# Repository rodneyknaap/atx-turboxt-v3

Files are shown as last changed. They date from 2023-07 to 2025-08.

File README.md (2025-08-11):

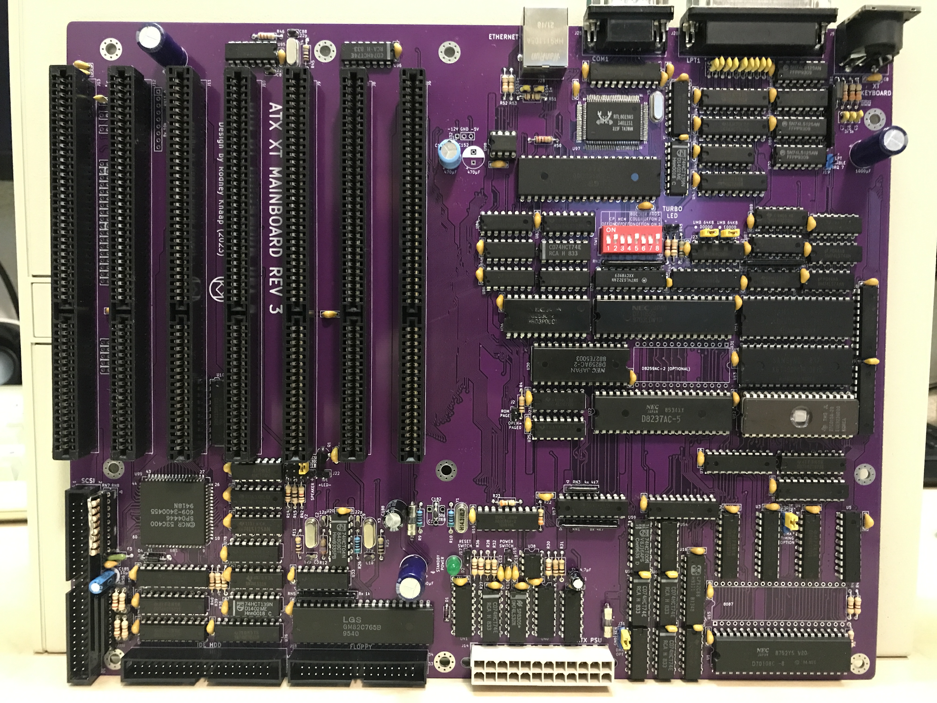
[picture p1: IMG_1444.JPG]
Photo of the assembled ATX Turbo XT mainboard V3 PCB


# ATX Turbo-XT Mainboard V3

I hereby publish the third revision of my ATX Turbo-XT mainboard design.
I had my doubts whether it would be wise to share my project, however the fact that keeping technology to myself prevents others to benefit from it made me decide for a release.
Open source is in my opinion the most important concept for all technology of mankind to move into the future in a way which has the potential to benefit all of us.

## Purpose and permitted use, cautions for a potential builder of this design

This project was created for historical purposes out of love for historical computing designs and for the purpose of enabling computing enthousiasts with a sufficient level of building and troubleshooting expertise to be able to experience the technology by building and troubleshooting the hardware described in this project.

## Besides the GPL3 license there are a few warnings and usage restrictions applicable:

No guarantees of function or fitness for any particular or useful purpose is given, building and using this design is at the sole responsibility of the builder.

Do not attempt this project unless you have the necessary electronics assembly expertise and experience, and know how to observe all electronics safety guidelines which are applicable.

It is not permitted to use the computer built from this design without the assumption of the possibility of loss of data or malfunction of the connected device. To be used strictly for personal hobby and experimental purposes only. No applications are permitted where failure of the device could result in damage or injury of any kind.

If you plan to use this design or any part of it in new designs, the acknowledgement of the designer and the design sources and inspirations, historical and modern, of all subparts contained within this design should be included and respected in your publication, to accredit the hard work, time and effort dedicated by the people before you who contributed to make your project possible.

No guarantee for any proper operation or suitability for any possible use or purpose is given, using the resulting hardware from this design is purely educational and experimental and not intended for serious applications. Loss of data is likely and to be expected when connecting any storage device or storage media to the resulting system from this design, or when configuring or operating any storage device or media with the system of this design.

When connecting this system to a computer network which contains stored information on it, it is at the sole responsibility and risk of the person making the connection, no guarantee is given against data loss or data corruption, malfunctions or failure of the whole computer network and/or any information contained inside it on other devices and media which are connected to the same network.

When building this project, the builder assumes personal responsibility for troubleshooting it and using the necessary care and expertise to make it function properly as defined by the design. 
You can email me with questions, but I will reply only if I have time and if I find the question to be valid. Which will probably also lead to an update here.
I want to primarily dedicate my time to new project development, I am not able to do any user support, so that's why I provide the elaborate info here which will be expanded if needed.

# Factors for proper operation and stability

Timing issues are likely to occur which require certain components to be of a suitable sufficient type to be able to meet the timing requirements for proper function. The prototype of the developer is proof of concept, please refer to the detailed partslist provided which includes type and manufacturer for all ICs where necessary, however each new build may pose it's own challenges to bring it to success. This design is by nature not a turnkey solution and will only function when using all the components of similar timing and behaviour as was used in the prototype. Determining the right components may likely be experimental in nature and require expertise, experience, effort and persistance.

Specifically the databus control transceivers and DMA handshaking circuits are most sensitive to exact types of at least equivalent timing as the types specified in the IC list, so refer to that list. The choice of DMA controller is a matter of trial and error, not all DMA controller chips are of sufficient timing to control a floppy disk using this design, specifically a floppy disk format poses the most exact testing situation to ensure proper DMA operation. Manufacturing date variations also may result in timing variations of the DMA controller. If the DMA handshake logic ICs are of faster types, this may also allow a more broad range of DMA controller ICs to work properly. Though I have not verified this with tests. Theoretically, using lower voltage logic or programmable logic may provide faster timing, though I have not chosen these methods in my design because I already achieved proper timing with the components I had available.

The 24Mhz oscillator load capacitors should be used as specified in the design, the oscillator should be checked to operate properly. If the total load (PCB capacitance + load capacitors) is too high, the oscillator will not run reliably and this will cause crashes, devide by zero errors, freezing, resets etc. Therefore ensure to observe the load capacitance suitable and proper stable operation of the oscillator. The ground shielding of the PCB traces of the clock signals comprise an addition to the load capacitance so the load capacitors themselves can be lower. For a turbo XT, it is not required to use two 8284 chips, one is sufficient. The DMA controller can properly operate on a fixed 50% duty cycle clock within the speed range of the chip so that is what I have provided. I derived the XT system clocks (keyboard, timer chip) from the DMA clock signal, which are also all fixed clock signals and do not vary when switching the CPU speed. CPU speed can be switched with the keyboard CTRL-ALT-num+ and CTRL-ALT-num- as controlled by the Super PC/Turbo XT BIOS (perfected by Jon Petrosky and Ya'akov Miles) at any moment without crashing the CPU. At least, I was not able to get the PC to crash by switching the speed at various moments.

# Important notice about capacitors at edge of mainboard
There have been many capacitor footprints added to the edge of the ISA bus, on the left of the mainboard. These do not all need to be populated, but are instead intended for termination of signal reflections, in case there are some issues occuring. Specifically, active high signals may be sensitive to noise generated from reflections. The best example is the RESETDRV signal on the ISA bus. If there is too much noise on such a signal it may cause certain I/O ICs such as UARTs to operate erroniously. For this reason the onboard UART RESET input has been purposely grounded. Use a 2.2nF capacitor for RESETDRV at least.  

I want to caution against soldering in all of these parts, that is not the purpose of these footprints. Start with the RESETDRV capacitor, and then first get the system up and running, and then do scope measurements with your target CPU clock frequency to see if any interference or ringing stands out. It's easy to test by inserting a capacitor into the footprint holes and measure/test the resulting effect on a certain signal if it looks particularly bad on a scope. Don't solder in all these capacitors right away because I can't predict how this will impact the entire system operation by changing all the impedances. These footprints are only intended to solve any noise, ringing or extreme interference on signals, and is not a default configuration to include all of these without a clear reason leading to doing that. In fact, less capacitors needed would be better overall for the system operation.

Databus transceivers which drive the ISA bus should be chosen of LS245 types which give better stability results. HCT types have better amplitudes but are more sensitive in the system. Refer to the IC list for best choices, though you could experiment after achieving a stable system to see if more HCT types are possible. For driving the SRAM memory databus, HCT types are fine.

This is an advanced project which contains many components, therefore the maximum care should be applied and maintained when soldering the PCB. Where using IC sockets, ensure they are proper quality sockets which are solid enough to create a reliable connection to the ICs inserted. Using sockets on DMA control circuits would be an advantage for trial and error testing to determine proper timing is reached. Use care to observe all IC orientations which differ due to layout considerations. Some ICs are tightly packed on the PCB, so first solder the ICs or sockets, then solder the decoupling capacitors. Also see the photo above for an example.

After soldering the project, it's a strong requirement to use proper lighting and magnification and systematically inspect all soldering points to detect any short circuits or open solder joints before powering up the system for testing. Short circuits which are not detected will probably damage ICs and introduce hidden defects into your project which will be even more difficult to detect after the damage is done. Fuses are put into the 5V and 12V lines which should blow on shorts or overcurrent. Keep in mind that the amount of current an ATX PSU can generate before it goes into protection mode also requires care of the project builder to ensure no short circuits occur which could destroy components or PCB traces.

If you do not agree or do not wish to accept the above risks, cautions and usage terms, do not make any attempts to build and operate the hardware in these design specifications.
It is not allowed to pass on this design to others without requiring them to read this entire document carefully and accept all of the terms.

# Acknowledgements

This project was inspired by:
- IBM Corporation who introduced the industry standard PC concept and design schematics
- Taiwanese clone XT builders who produced their own modifications in the turbo XT which also inspired this project
- testing with the Super PC/Turbo XT BIOS https://www.phatcode.net, 
- Sergey's HD floppy drive BIOS extension https://github.com/skiselev/floppy_bios
- concept and software of the XT-IDE universal BIOS https://www.xtideuniversalbios.org
- datasheets, application notes and specifications by:

LG Semiconductors (Goldstar) (GM82C765 FDC, GM16C550)
Standard Microsystems Corporation (FDC37C65C datasheet, FDC register access table)
Texas Instruments (GD75232)
Realtek (RTL8019AS)
NCR (53C400 SCSI)

Acknowledgements of people who were instrumental in preceeding developments upon which this design was elaborated:

[IBM PC development team](https://www.ibm.com/ibm/history/exhibits/pc25/pc25_birth.html)
[Some historical info](https://arstechnica.com/gadgets/2017/06/ibm-pc-history-part-1/)
[Bill Lowe](https://www.ibm.com/ibm/history/exhibits/builders/builders_lowe.html)
[Don Estridge](https://www.ibm.com/ibm/history/exhibits/builders/builders_estridge.html)

[Sergey Kiselev](http://www.malinov.com/Home/sergeys-projects/xi-8088)
[His HD Floppy BIOS](https://github.com/skiselev/floppy_bios)
I was inspired after seeing and reading about his 8088 projects, he also created the HD floppy BIOS extension.
 
[Super PC/Turbo XT BIOS by Plasma (Jon Ρetrosky and Ya'akov Miles)](https://www.phatcode.net)
An excellent BIOS for XT machines, far superior in stability and function to anything else I have tested.

Tilmann Reh and others (16 bit to 8 bit translation of IDE I/O in computer hardware for example as described in TCJ #53)
I have used my own adaptation of [J. Chapman's version(Glitchworks)](https://minuszerodegrees.net/xtide/rev_4/XT-IDE%20Rev%204%20-%20general.htm) of XT-IDE schematic after extensive testing with several circuit and component variations on an Amstrad PPC640. I studied all revisions of the circuits first before creating my own variations.
More information about the creation of XT-IDE hardware can be found [here](https://minuszerodegrees.net/xtide/XT-IDE%20-%20Basics.htm).

[XT-IDE universal BIOS project development team for developing the XT-IDE BIOS](https://www.xtideuniversalbios.org)
Amazing and extremely efficient software, fast disk access for XT and various AT computers.
Works with every IDE drive I have tested. Still under active development earlier in 2023.

All source data remains the copyright of the original creators and must be respected.
This design is only released for hobby computing enthousiasts and educational purposes, no profit is to be made from this design or derived work from it.

I have taken time to respectfully include all the above acknowledgements. If anyone or anything is left out, that is absolutely not intentional, please contact me and I will update this page.

After elaborately studying the available source design files which inspired the system, I conceived this design with my own variations, circuit additions and changes which I see as improvements according to my personal design views and preferences. Some logic types I have changed to get a better schematic perspective on an entire circuit area. My purpose was a good clear recreation in my own method, not to exactly copy the original. I have removed the DRAM refresh and parity check logic from the design.

I have designed most of the I/O control circuits using the chip manufacturer datasheets to determine the proper interfacing methods, ports etc suitable for this XT design.

# ROM BIOS

The choice of BIOS for operation of this mainboard is up to the builder, the BIOS used in the operation of my build works well, and is composed as follows, top to bottom segments in the ROM image are:

0k-8k    Super PC/Turbo XT BIOS (project by Jon Petrosky and Ya'akov Miles)  

8k-16k   XT-IDE BIOS file (by XT-IDE universal BIOS team)  
The BIOS must be configured to port 300/308 and XT-IDE v2 ("Chuck mod") hardware.
The BIOS image is to be corrected for checksum=0 by XT-IDE config software and then should be saved back into the BIOS.
Using an 8088 you need the ide_xt.bin, for the NEC V20 you can use the ide_xtp.bin.  

16k-24k  XT HD-Floppy BIOS extension (by Sergey Kiselev)  
Configuration of floppy drive config bytes according to instructions provided by Sergey.
It's best to configure your floppy drive configuration by setting the appropriate bytes in the image to correspond with the floppy drives you plan to connect.
All drives should be set to drive select 1 (counting from 0) and the standard floppy cable twisting should be used to choose the first and second drive.
Since it's a relatively modern FDC, floppy termination should be moderate for example 1k, and doesn't need to be done on all the floppy drives.
Possibly, floppy drive termination on the drives themselves can even be left out or only present on one drive.
The less resistance on the terminated signals, the less load on the FDC pins. 150 ohms is really too low a resistance to use and I recommend removing these when found on a drive and at least replacing with 1k, or leaving them out.  

24k-64k  Remaining 40k  program with blank space "00" hex codes.  
This comprises a 64k BIOS image, the design accommodates two BIOS images in the 128k ROM, the page to be used can be switched by a jumper or switch. For testing it's advised to program two identical BIOS images into the ROM first. Initially it's best to use an EPROM which cannot be erased by software if there is any software trying to write into the BIOS region. If you like to add other BIOS images you can simply include them into the BIOS image file since there are 5 segments of 8k available.  

What I did is to create two variations of the 64k BIOS, one which includes a DD 5,25 floppy drive, and the other includes a HD 5,25 floppy drive. I have added switches to the DS1 jumpers of my two 5,25 drives which enables to leave both connected to the floppy bus simultaniously. The switches change both the BIOS image selection and the drive selects. Using both a DD and HD 5,25 drive makes sure that any floppy disks are properly read and written, due to matching the proper track width compatibility of the original intended drives to the respective disks. In both of my BIOS versions, I have defined drive A: to be a 1,44MB HD 3,5 inch drive. Drive B settings contain the DD and HD versions of the 5,25 drives.

In order to create the BIOS image I used a cmd batch command.  

`copy /b blank8k.bin + blank8k.bin + blank8k.bin + blank8k.bin + blank8k.bin + floppy22_DD.bin + IDE_XTP.BIN + pcxtbios_phatcode.bin biosrom64k_dd_fdd.bin`  

`copy /b blank8k.bin + blank8k.bin + blank8k.bin + blank8k.bin + blank8k.bin + floppy22.bin + IDE_XTP.BIN + pcxtbios_phatcode.bin biosrom64k_hd_fdd.bin`  

`copy /b biosrom64k_hd_fdd.bin + biosrom64k_dd_fdd.bin !biosrom_floppy22_switch_dd_hd_config.bin`  

This should result in a 128kb file named !biosrom_floppy22_switch_dd_hd_config.bin  

The onboard RTL8019AS adapter is configured using the 93LC46 EEPROM. This EEPROM can be programmed using a programmer, I will provide a dump image of my example chip. The image also contains the MAC address so this should be varied slightly in your implementation.  

The LPT port does not need interrupt 7 to operate so the jumper should be left open because of limited interrupts available in an XT.
DMA timing jumpers provide alternatives for testing purposes, the settings indicated by the asterisk are defaults.  

Resources (besides obvious internal base XT chips):  

IO Ports:  
0300	XT-IDE  
0308	XT-IDE  
0340	LAN  
0378	LPT  
03F8	COM1  

IRQ list:  
IRQ0	system refresh timer  
IRQ1	Keyboard  
IRQ2	available  
IRQ3	LAN  
IRQ4	COM1  
IRQ5	available  
IRQ6	FDC  
IRQ7	SCSI  

DMA list:  
DMA 0	refresh dummy DMA  
DMA 1	free  
DMA 2	FDC  
DMA 3	free  

For the SCSI bus general practises for termination apply. The 53C400 is very solid, stable and fast and works really well with LS2000 drivers.
A SCSI bus is an ideal period correct way to provide plug-in storage and CDROM access for an XT PC.  

I operate my XT PC with a VGA card, the Video 7. Perhaps others like CGA or EGA which requires the correct dipswitch settings. I don't own any CGA monitor and besides I want to be able to use windows 3.0, play certain games and view photos in full VGA format on a modern monitor. I have tested a ATI Small Wonder card to operate properly on the composite output on a CRT.  

The schematic diagram is intentionally created as a single sheet for fastest navigation back and forth between various circuit areas. Such a large single sheet does slow down editing somewhat but it's an acceptable compromise in my opinion once you get used to it. It's not the "fullness" of the schematic, but the sheet size which slows down the schematic editor somewhat, which can be lessened by occasionally saving and closing the schematic, and then opening it again. Schematic and PCB design are made in KiCad 5.1.7. I know this is not the latest release however I am used to working in this version and I don't see a need to change that for now since it has proven to be sufficient for this purpose.  

This KiCad version is confirmed to be fully compatible with screenshots of JLCPCB guidelines of settings for creating the files for manufacturing. 
I will be including my own KiCad library additions in the source files which need to be unpacked into the appropriate kicad installation shared library folders.  

# Update 24-12-2023:  
I have done further testing with ALS and F type logic ICs to improve on the DMA timing, which allows for supporting a wider range of 8237-clone DMA controllers to function completely in the system. This is vitally important for supporting floppy disk writing and formatting, and for supporting sound samples to be played back through a soundblaster compatible soundcard for example in DOS games.  
The result of my testing work is that after replacing with these ICs the DMA timing is much improved:

U24 - 74ALS573 (no F type available at the moment)  
U55 - 74F08  
U58 - 74F74  
U59 - 74F00  
U60 - 74F74  

These recommended ICs are now also included in the detailed txt partslist included in this GitHub project.  

I will not be further revising this design since I view it as completed.  

I was contacted by A-Small-Mice who created his own modified version of Dante's ATX I/O Shield for the project.
I merged his request into the project so you can find the necessary files in the main directory.
Thanks A-Small-Mice!

My next project is a 286 AT mainboard design comperable to the IBM 5170 and similar PCs, without the use of a chipset.  
I am currently using a IBM 5170 type 3 mainboard as a reference and test board for my 286 project.
I found that other clone boards I have tested so far contain errors and operate unreliably.
The only 100% reliable specimen of this design phase of PC development I have found and was able to test myself is the IBM one.  

After the 286 I will attempt to integrate the 486 SLC in a subsequent future revision. 
I am also working on a 5150 recreation in a complete modern ATX format, because I want an early 8 bit PC compatible computer which can still support a cassette interface for saving and loading programs.  

# Notice about future follow up project plans  
After gaining substantial experience using CPLD logic in PC projects, I plan to create a REV4 PC/XT design using one or more CPLD chips.
The idea is to achieve a high level of integration, improving the bus structure, and I want to revisit including an RTC as well because I think I have discovered what the problem previously was.  

Very likely the new XT design will be more compact than this project so possibly it will become a much smaller PCB.
Additionally, it will contain a lot less components than this project. And I will probably experiment with replacing the bus controller ICs with CPLD logic based designs as I have done with the 286 CPU. This work also depends on how much documentation about the 8088 cycle operation I will find, if the diagrams etc are enough information for me to be able to work with. Another upgrade will be that a USB mouse connection will be included based on the usb to serial project by limeprogramming. So the 12V level shifter and COM1 port will be replaced with a USB header for a USB mouse and there will be a RP2040 inserted into the board using an angled connector. I will publish more about all the future design changes later.  

As soon as the new design is taking shape, I will create a new repository for it.  

Thanks for your interest in this project. I would appreciate a message if anyone has built this mainboard.  

kind regards,  

Rodney

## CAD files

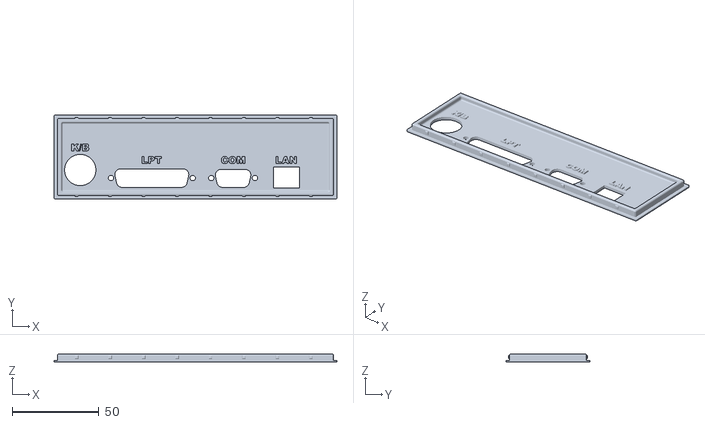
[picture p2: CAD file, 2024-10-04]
IO_Shield_for_ATX_XT.stl
162.8 x 48.5 x 4.75

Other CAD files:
IO_Shield_for_ATX_XT.f3d

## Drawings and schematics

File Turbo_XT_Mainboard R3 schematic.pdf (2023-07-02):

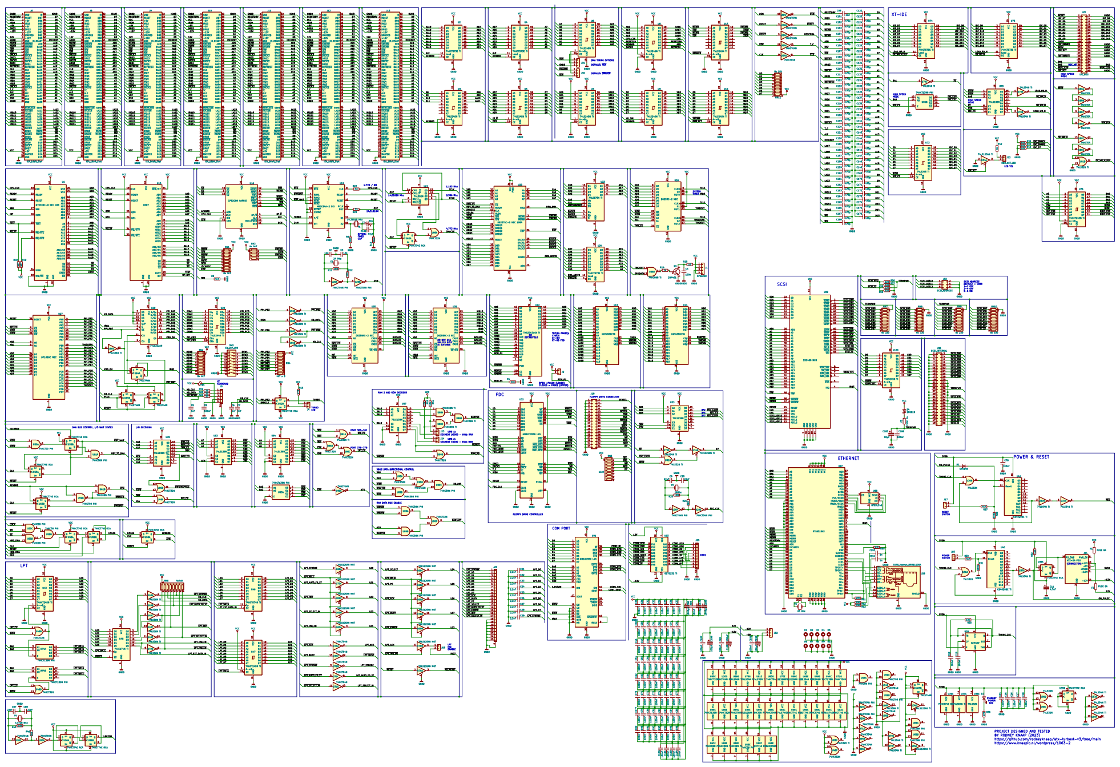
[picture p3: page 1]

GND 1 GND 10 SMEMW 11 SMEMR 12
IOR 14 DACK3 15 DRQ3 16 DACK1 17 DRQ1 18 REFRESH 19 RESET 2 CLK 20

IRQ3 25 DACK2 26 TC 27 ALE 28 VCC 29 +5V 3 OSC 30 GND 31

1 AD6 10 AD5 11 AD4 12 AD3 13 AD2 14 AD1 15 AD0 16 CLK 19 AD14 2 GND 20 RESET 21 READY 22 BUSY 23 QS1 24 QS0 25 S0 26 S1 27 S2 28 AD13 3 RQ/GT0 31
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

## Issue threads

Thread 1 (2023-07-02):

GLaBIOS compatibility questions

640-KB, 2023-07-02:
Hi Rodney,

First of all congrats on releasing this - it looks extremely cool and is something I'd definitely like to build. :)

Anyway, I'm the author of GLaBIOS and i387DX on TRW Discord suggested maybe we connect about hardware/BIOS compatibility?  I'm always adding hardware support for new projects so would love to be part of this.

Happy to talk here, or are you on Discord?

640KB

rodneyknaap, 2023-07-03:
Hi 640KB,

Thanks for your interest and getting in touch, that's very kind of you.
I also responded on the dosreloaded.de forum.

I am also interested in your BIOS. I really hope the GLaBIOS could work on my system because I love the work and I saw many customizations in the source code.
That kind of work is really modern and I feel it matches with my hardware.

About my design, it basically uses the same keyboard circuits as the original IBM 5160 and Turbo XT clones made in Taiwan.
There is no keyboard controller, it's all done in the 8255 PIO chip and the 74LS322 just as in the IBM designs.
The keyboard I use is a Cherry G80-1000 with the dipswitch in "XT" mode.

I am not sure why the TOGGLE.COM causes the strange configuration of the keyboard to input numbers on the prompt instead of the arrow key function. It almost seems as it's confusing scancodes of the arrow keys with the number keys in the numerical section of the keyboard. TOGGLE.COM only changes the typing mode to CAPS and enables the numerical keys by default. On the XT I did notice before that TOGGLE.COM works in a strange way with the phatcode BIOS too, because it does turn on CAPs typing and numlock, however the LEDs do not turn on. I guess doing that requires an actual keyboard controller on the mainboard, I am not sure.

After taking TOGGLE.COM out of my AUTOEXEC.BAT, I could see that DOSKEY functioned normally to recall previous DOS commands instead of showing numbers on arrow presses. So TOGGLE.COM seems to confuse the keyboard routines somehow.

About my UMB memory, it is very simple, it's enabled with two jumpers in my memory decoder. The jumpers are on which means that the memory is accessible in the D0000 and E0000 memory regions. CLEARMEM.SYS zeroes out the area and USE_UMBS.SYS initializes it for usage as UMB RAM. The commands are as follows:

DEVICE=C:\DOS62\CLEARMEM.SYS D000 2000
clears the area starting at D0000h for a 20000h section of RAM.

DEVICE=USE_UMBS.SYS
initializes the UMB blocks. This driver works best when initializing an entire 128KB block.

I am not sure how the driver works, but I did find the source code, which might help you understand what happens:

```
;-------------------------------------------------------------------
;
; PROGRAM   Use!UMBs.sys - UMB manager for PC/XT/ATs
;
; PURPOSE   This program creates a device driver that will handle
;           calls for Upper Memory Blocks. In doing so, it gives
;           you the possibility to save conventional memory by
;           storing device drivers and resident programs in the
;           UMBs and hence save conventional memory.
;
; REQUIRES  It will work on any PC/XT/AT or higher, either with or
;           without extended memory. What you obviously *must* have
;           are UMBs, and MS-DOS Version 5.0.
;
; AUTHOR    Marco van Zwetselaar    Phone: **-31-30-313128
;           Oorsprongpark 5         FidoNet: Marco van.Zwetselaar
;           3581 ES Utrecht                  NetMail 2:281/701
;           The Netherlands         Utrecht, 7 Nov 1991
;
;-------------------------------------------------------------------
;
; IMPORTANT NOTE to the programmer
;
; I am only a beginner in assembly language, and haven't found out
; as yet how to create a .com file. When you recompile this program,
; take care you do that as a com file, and then rename it to a .sys
; file.
;
; I used an alternative method that you may use as well: I compiled
; it to .exe format and then removed the first (half?) sector. In
; fact, the first bytes in the final file should be:
;
; FF FF FF FF 00 E0 ...
;
; which are the bytes that start at nextDev. (Almost any device
; driver file should start with the first two words being FFFF (-1)).
;
;====================================================================
;
; THE ACTUAL ASSEMBLY CODE
;
;---------------------------------------------
; This is the structure of the request header; not stored in file
;
rh              segment at 0
org     02h
rh_cmd          db      ?               ;command-code
rh_status       dw      ?               ;return-code
org     0Eh
rh0_brk_ofs     dw      ?               ;end of driver offset
rh0_brk_seg     dw      ?               ;end of driver segment
rh              ends
;
;--------------------------------------------
; The driverheader

org     0h
zwetsUMB        segment public
assume  cs:zwetsumb, es:rh, ds:nothing

; any device driver will start with the following info:

next_dev        dd      -1
attribute       dw      0E000h
strategy        dw      strat
interrupt       dw      intr
dev_name        db      'I_LOVE_M'

;--------------------------------------------
; Storage space for pointer to Request Header

hdrptr  label   word
dw      ?,?

;--------------------------------------------
; Strategy: store pointer to Request Header:

strat   proc    far
mov     [hdrptr],bx
mov     [hdrptr]+2,es
retf
strat   endp

;--------------------------------------------
; Interrupt: The routine that fires the installrequest

intr    proc    far

push    ax
push    bx
push    es
pushf

les     bx, dword ptr [hdrptr]  ;point es:bx to ReqHeader
mov     [bx].rh0_brk_seg, cs    ;and already return the seg

; Remember that the device will only answer the init-request
; which is called by dos as it installs the driver.
; Any later calls will be ignored - they are not needed anyway.

mov     al, es:[bx].rh_cmd      ;commandcode into al
or      al, al                  ;is it 0 (=init)?
jnz     other                   ;   no => get off
jmp     inst                    ;   yes => install

other:  cmp     al, 10h                 ;is it legal call?
jbe     short dos               ;   yes => "Sorry"
mov     ax, 8003h               ;   no => "Unknown command"
jmp     short exit

dos:    xor     ax, ax                  ;"Sorry - not implememented"

exit:   or      ax, 0100h               ;Set done bit
mov     es:[bx].rh_status, ax   ;set return code

popf
pop     es
pop     bx
pop     ax

retf                            ; back to dos

intr    endp

;------------------------------------------------------
; Storage space for the addresses of free umb blocks

umb     struc
start   dw      ?
len     dw      ?
umb     ends

;you can add to the following list, as long as the last one is 0,0

free    umb     <0D000h, 1FFFh>   ;my only block (at d000, length 1fff)
umb     <0, 0>            ;space for extra block
umb     <0, 0>            ;and another block
umb     <0, 0>            ;The end of the blocks is marked
; with 0,0 DON'T REMOVE THIS!!!!!

;------------------------------------------------------
; This is the code for the actual UMB memory provider

umbreq  proc    near

push    ds
push    si
push    cx
push    bx

push    cs
pop     ds

mov     si, offset free
xor     cx, cx                  ;clear dx and use it to compare
xchg    dx, cx                  ;to largest found as yet - cx=size

search: lodsw                           ;read startsegment into ax
or      ax, ax                  ;is it 0
jz      fini                    ;   then buzz off
mov     bx, ax                  ;   otherwise store into bx
lodsw                           ;read length in ax
cmp     bx, 0FFFFh              ;is startsegm=ffff=given away
je      search                  ;   yes: then find next block
cmp     dx, ax                  ;   no: larger than largest upto now?
jae     szchk                   ;       no: check size
mov     dx, ax                  ;       yes: mark as largest

szchk:  cmp     cx, ax                  ;will it fit?
ja      search                  ;   no: search next

; YEAH! Found a block

mov     [si-4], 0FFFFh          ; mark as used
mov     dx, ax                  ; put blocksize in dx
mov     ax, 1                   ;say Succes
pop     cx                      ;still had bx on stack
jmp     short return

fini:   xor     ax, ax                  ;no fitting UMB
or      dx, dx                  ;is dx=0?, so largest found=0
jnz     sizerr                  ;   if not: problem with size
pop     bx                      ;   if yes: BH should stay intact
mov     bl, 0B1h                ;       and BL signals: out of UMBs
jmp     short return

sizerr: pop     bx                      ;BH remains intact
mov     bl, 0B0h                ;BL signals: there are smaller ones

return: pop     cx
pop     si
pop     ds
popf
retf

umbreq  endp

;------------------------------------------------------
; Storage space for old XMS-handler. The first byte stores WHETHER there
; was an XMS handler already (that didn't provide UMB services).
; The next two words specify its location.

isoldx  db      00h

oldxms  label word
dw ?,?

;------------------------------------------------------
; This is the small XMS manager that we install. It will only react
; to requests for UMBs (so when AH=10h). If not, it *should* pass
; control to the existing XMS manager - provided there is one. Or
; otherwise inform the caller that there is no eXt memory.

assume es:nothing, ds:nothing

umbctrlr:

jmp     short hookch            ;MUST be a *short* jmp
nop                             ; The nops are there because
nop                             ; a himem handler always start
nop                             ; with 5 special bytes.

hookch: pushf
cmp     ah, 10h                 ;is it a UMB request?
je      umbreq                  ;  yes: execute it
cmp     [isoldx], 0h            ;  no: is there an XMS-handler?
jz      Xreq1                   ;     no: give response like it
popf                            ;     yes: jump to old handler
jmp     dword ptr cs:[oldxms]

; Below is the code that will respond to non-UMB (and thus XMS-)
; requests when no XMS-manager is present. To nearly all requests
; (there are 11h) it will answer with AX=0000, meaning failure
; and BL=80, which gives the errormessage: not implemented.
; Only fns 00h and 08h are treated specially (as well as fn 10h, but
; that has been filtered out above - it's the UMB-request).

Xreq1:  cmp     ah, 0h                  ;req 00h = get XMS version
jnz     Xreq2
mov     bx, 0h                  ; ->internal revision nr=0
mov     dx, 0h                  ; ->HMA not present
jmp     short byebye

Xreq2:  cmp     ah, 08h                 ;req 08h = query extended mem
jnz     Xreq3
mov     dx, 0h                  ; ->0k extended memory

Xreq3:  mov     bl, 80h                 ; ->error: not implemented

byebye: mov     ax, 00h                 ; ->failure (always the case)
popf
retf

;------------------------------------------------------
; Storage space for old interrupt vector 2f

old2f   label   word
dw      ?,?
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
rodneyknaap, 2023-07-03:
Hi 640K,

I just did some more testing, and when bypassing config.sys, I can at least load MSD.EXE normally.
So that would indicate that the USE!UMBS driver which is not loaded but providing any actual UMBs is the reason for MSD,EXE not fully loading. So that is a matter you can ignore since it is likely to be resolved when the UMB area is functional.

I have tested Norton Commander with FreeDOS which shows the same problem, no response from keyboard or mouse, but I am hearing soft key beeps from the speaker. If I keep typing a lot, there will be a system halt and I need to reset to get out of it, CTRL-ALT-DEL is not working then anymore. Before the system halt I can CTRL-ALT-DEL to get out of Norton Commander.

Kind regards,

Rodney

rodneyknaap, 2023-07-03:
Hi 640K,

I have burned an EPROM with a Phoenix XT BIOS Version 2.27 from 1986 after I prepared a 5,25
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

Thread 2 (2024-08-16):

R26's Value?

A-Small-Mice, 2024-08-16:
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
 I am building the ATX Turbo XT according to the given BoM, but I’m having trouble determining the value of R26. Is it 510 ohms or 2.2K ohms?

rodneyknaap, 2024-08-18:
I checked this, on my last build I used 510 ohms for R26.

A-Small-Mice, 2024-08-18:
Thank you for your response!

A-Small-Mice, 2024-10-29:
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

It seems that the values for C100, C152, and C188 are incorrect. According to the BoM, they should be 100uF, but they actually appear to be 470uF.

A-Small-Mice, 2024-10-29:
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

The value of ***R36*** is 470 ohms, but depending on the type of LED used, a higher resistance may be more suitable. When I used a 470-ohm resistor, the white LED was too bright, making it hard to look directly at the mainboard. Switching to a 2.7k-ohm resistor reduced the brightness significantly, but it was still too bright, so I added a cap printed with a 3D printer. In my case, I think a 4.7k-ohm resistor would reduce the LED brightness to a more comfortable level.

rodneyknaap, 2024-10-29:
Ouch, yes, especially blue or white leds can be painful to the eyes. At my age my eyes have become much more sensitive to this. But everyone should be careful with white and blue LEDs, they are much too bright. So lately I am avoiding these LED colors and prefer to use yellow, red and green LEDs. Maybe it's not so beautiful and modern looking als blue ones but a lot less hard on the eyes. If you think 4,7k is better, do try it out, even a blue or white LED can be "tamed" finally. :) It's amazing how efficient these LEDs are compared to in the 1980s! You also could wire up a potmeter to adjust the LED brightness to your satisfaction, and then you will know the approximate value you need. These LEDs if they are run too high current, they will soon fail and be broken. Also they are much more sensitive to prolonged soldering heat so the faster they are soldered, the better.

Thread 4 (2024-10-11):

The MAC Address is always AA:AA:AA:AA:AA:AA

A-Small-Mice, 2024-10-11:
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

I was deeply impressed by your project, so I created my own ATX Turbo XT motherboard. There are still a few important issues, but the one that concerns me the most is the LAN problem. I used the dump image of the 9346 chip you provided, but the MAC address shows up as **AA:AA:AA:AA:AA**, and the DHCP server is not connecting. When I remove the 9346 chip from the motherboard, the MAC address becomes **00:00:00:00:00:00**. What should I do?

A-Small-Mice, 2024-10-11:
I've learned a lesson that I shouldn't attempt anything when I'm tired. The cause was too simple: incorrect I/O address assignment.

rodneyknaap, 2024-10-11:
Hi A-Small-Mice, thanks for sharing a photo of the system. It's the first build photo I have seen so far. The system took countless hours to design and develop in my spare time so it's nice to see someone else attempting to build this. No problem that you shared this issue because by doing so you also created a solution in case someone else observed this behavior from the Realtek chip. Remember, I have already built and tested this whole system and found no further issues on the prototype. Having said that, there are of course no guarantees! But still, I love to get some information how others fared in building the system! Wish you good luck on your work!

A-Small-Mice, 2024-10-29:
Thank you sincerely for sharing this wonderful project that allowed me to build it. I have wanted an XT motherboard made in the ATX form factor **without using a motherboard chipset** for a long time, and you’ve made my dream come true. The best I can do to express my gratitude is to show you how well I am using this amazing project. Here are a few more photos of the ATX XT that I built...

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

And There is enough space in the 128KB ROM to fit 32KB of ROM BASIC, so I created the system ROM as follows:

copy /b blank8k.bin + floppy22_144_360.bin + ide_xt.bin + CAS_U29.bin + CAS_U30.bin + CAS_U31.bin + CAS_U32.bin + pcxtbios.bin xt_64kb.bin

copy /b xt_64kb.bin + xt_64kb.bin xt_128kb.bin

rodneyknaap, 2024-10-29:
Hi A-Small-Mice,

A very beautiful build! I particularly love the red/brown color bypass capacitors, they have a beautiful contrast with your black solder mask mainboard, a great combination and old school effect in your build.

And my compliments on the HDD front you used with the very old school looking HDD LED inside it.
This also brings a original legacy feeling to your build when seeing it.

My congratulations on this great system, I really love how it turned out!
After not using my XT build for a while, when I power it on again, I enjoy the experience every time.
The XT is simply a charming system. :)

Thanks for sharing these photos, I much appreciate it!

Kind regards,

Rodney

Closed 2024-10-11.

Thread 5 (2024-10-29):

DMA Timing Issue

A-Small-Mice, 2024-10-29:
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

When building my ATX Turbo XT, I faced significant challenges in adjusting the DMA timing. The motherboard built according to the BoM you provided works well at 4.77 MHz, but at 8 MHz, issues arise, such as the floppy disk not reading correctly or digitized sound not playing properly. I received help from CHARLIE IM, known for assembling a Soviet Poisk-2 with American parts, and managed to resolve the DMA timing issue by making adjustments according to the following table. I hope this information will be helpful to others as well.

| Part# | Orginal     | New                |
| ----- | ----------- | ------------------ |
| U1    | uPD70108C-8 | uPD70108C-8        |
| U2    | HCT573      | CD74HCT573E        |
| U3    | LS245       | **SN74HCT245N**    |
| U4    | HCT573      | CD74HCT573E        |
| U5    | HCT245      | SN74HCT245N        |
| U6    | LS245       | **SN74F245N**      |
| U7    | LS245       | **SN74F245N**      |
| U8    | LS245       | **SN74F245N**      |
| U9    | HCT245      | **SN74LS245N**     |
| U10   | HCT245      | **SN74LS245N**     |
| U11   | N/A         |                    |
| U12   | TMS27C010A  | TMS27C010A         |
| U13   | K6T4008C1B  | **AS6C4008-55PCN** |
| U14   | K6T4008C1B  | **AS6C4008-55PCN** |
| U15   | I8087       | C8087              |
| U16   | CP82C88     | CP82C88            |
| U17   | LS245       | **SN74ALS245AN**   |
| U18   | N/A         |                    |
| U19   | M82C84A-2   | M82C84A-2          |
| U20   | HCT04       | SN74HCT04N         |
| U21   | LS92        | SN74LS92N          |
| U22   | uPD8237AC-5 | uPD8237AC-5        |
| U23   | LS670       | SN74LS670N         |
| U24   | HCT573      | **SN74ALS573CN**   |
| U25   | LS138       | HD74LS138P         |
| U26   | uPD8253C-2  | uPD8253C-2         |
| U27   | uPD71055C   | uPD71055C          |
| U28   | LS322       | SN74LS322AN        |
| U29   | LS244       | SN74LS244N         |
| U30   | uPD8259AC-2 | uPD8259AC-2        |
| U31   | uPD8259AC-2 | uPD8259AC-2        |
| U32   | GM82C765B   | GM82C765B          |
| U33   | LS138       | DM74LS138N         |
| U34   | LS125       | SN74LS125AN        |
| U35   | N/A         |                    |
| U36   | LS32        | SN74LS32N          |
| U37   | LS04        | SN74LS04N          |
| U38   | NE555P      | NE555P             |
| U39   | HCT74       | SN74HCT74N         |
| U40   | CD4020BE    | CD4020BE           |
| U41   | CD4020BE    | CD4020BE           |
| U42   | N/A         |                    |
| U43   | HCT245      | **SN74LS245N**     |
| U44   | HCT139      | **GD74LS139**      |
| U45   | LS174       | SN74LS174N         |
| U46   | HCT574      | MM74HCT574N        |
| U47   | HCT245      | **SN74LS245N**     |
| U48   | HCT32       | **SN74F32N**       |
| U49   | LS06        | SN74LS06N          |
| U50   | N/A         |                    |
| U51   | N/A         |                    |
| U52   | N/A         |                    |
| U53   | N/A         |                    |
| U54   | HCT04       | SN74HCT04N         |
| U55   | HC08        | **SN74F08N**       |
| U56   | HCT74       | SN74HCT74N         |
| U57   | N/A         |                    |
| U58   | HCT74       | **74ALS74AN**      |
| U59   | HCT00       | **SN74F00N**       |
| U60   | HCT74       | **SN74F74N**       |
| U61   | HC08        | **SN74LS08N**      |
| U62   | HCT74       | **SN74LS74AN**     |
| U63   | N/A         |                    |
| U64   | LS74        | SN74LS74AN         |
| U65   | LS74        | SN74LS74AN         |
| U66   | LS06        | SN74LS06N          |
| U67   | N/A         |                    |
| U68   | LS125       | SN74LS125AN        |
| U69   | LS125       | SN74LS125AN        |
| U70   | LS125       | SN74LS125AN        |
| U71   | HCT04       | SN74HCT04N         |
| U72   | N/A         |                    |
| U73   | LS245       | **SN74HCT245N**    |
| U74   | HCT573      | CD74HCT573E        |
| U75   | HCT573      | CD74HCT574E        |
| U76   | HCT245      | SN74HCT245N        |
| U77   | N/A         |                    |
| U78   | LS138       | DM74LS138N         |
| U79   | LS04        | SN74LS04N          |
| U80   | HCT04       | SN74HCT04N         |
| U81   | LS32        | HD74LS32P          |
| U82   | N/A         |                    |
| U83   | LS138       | **SN74HCT138N**    |
| U84   | LS138       | **SN74HCT138N**    |
| U85   | HCT139      | CD74HCT139E        |
| U86   | HCT32       | MM74HCT32N         |
| U87   | LS138       | DM74LS138N         |
| U88   | HC08        | **SN74LS08N**      |
| U89   | HC08        | **SN74LS08N**      |
| U90   | HCT32       | **HD74LS32P**      |
| U91   | GM16C550    | TI16C550AN         |
| U92   | N/A         |                    |
| U93   | GD75232     | GD75232            |
| U94   | N/A         |                    |
| U95   | HCT04       | 74HCT04N           |
| U96   | HCT74       | SN74HCT74N         |
| U97   | RTL8019AS   | RTL8019AS          |
| U98   | HT93LC46    | 93LC46B-I/P        |
| U99   | 53C400      | 53C400             |
| U100  | HCT245      | **SN74LS245N**     |

rodneyknaap, 2024-10-29:
Hi A-Small-Mice,
I have read your component list which lead you to a successful assembly, congratulations on your work.

When I worked on my prototype, which is clocked at 8MHz, I also spent time debugging the system. The way I went about it is similar to what you have done, by swapping logic types in certain key locations, the timing of the system is shifted. Some locations are more critical than others, for example the 74HC74 D-latches in the DMA arbitration circuits are particularly sensitive. Also changing the 74LS138 decoder logic types will shift the chip selects which may help shifting the timing in the right spot. After you have solved the timing issues, you may find that you can swap back other IC locations to the original values and the system will continue to work fine.

Indeed it is helpful to have some 74Fxx logic ICs for the areas which need to be the fastest. The photo you posted looks to me like the IOCHRDY processing may have been the issue. I didn't have this problem myself on the XT, but on my AT design this was the initial issue causing VGA screen memory updates to get missed in many locations. I shifted the ready enable timing to resolve it in the AT. Similar things could be going on in the XT.

The problem is, when you use these TTL ICs, some may have significant different timing from the ones I used. Even if the type indication is identical, the timing will be different because the different manufacturers used different chip fabrication methods. These also continued to develop over the years and a newer part may have different timing, even from the same brand. Also the DMA controller timing will vary in my experience, which will in turn influence the DMA arbitration timing because the controller has a different response time.

On the other hand, having so many logic areas does at least provide more ways to shift the timing where you want with different logic families. So anyone constructing this design will do well to keep a stock of different logic types especially for the 74HC08, 74HC74, and the data transceivers. The address latches are much less sensitive parts in my experience.

Another example is the XT-IDE design which may be somewhat relevant for this project. There, swapping logic types for the decoders and delay circuits makes all the difference between a working and not working IDE interface.

Great job, and thank you for sharing the list and information, no doubt this may help others.

After overcoming your initial struggles, your system will now surely feel even more precious to you. :)
And you learned a lot about system timing on the way there!

I have similar sentiments after a long period of development. I had a lot of struggles with bad IC sockets from Chinese sellers. One was so loose that some of the keystrokes didn't even arrive on the bus. One should not buy cheap IC sockets! ;)

Kind regards,

Rodney

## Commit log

2023-07-02 Add files via upload
    Cad files are updated with tested IC types, please carefully read the description.
    [Turbo_XT_Mainboard R3.sch]
2023-12-24 Replaced several IC types with F and ALS logic to support best DMA timing
    Tested with about 10 NEC branded D8237AC-5 controllers with 100% success to access and format floppy disks. (dec 2023)
